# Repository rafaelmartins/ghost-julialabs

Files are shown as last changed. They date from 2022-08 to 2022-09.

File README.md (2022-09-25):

# ghost-julialabs

PCI para o desafio de halloween 2022 do canal [julialabs na Twitch](https://www.twitch.tv/julialabs).

Layout baseado na skin básica de fantasma do jogo Among Us.

## Hardware

### Placa de Circuito Impresso

placa de circuito impresso - frente
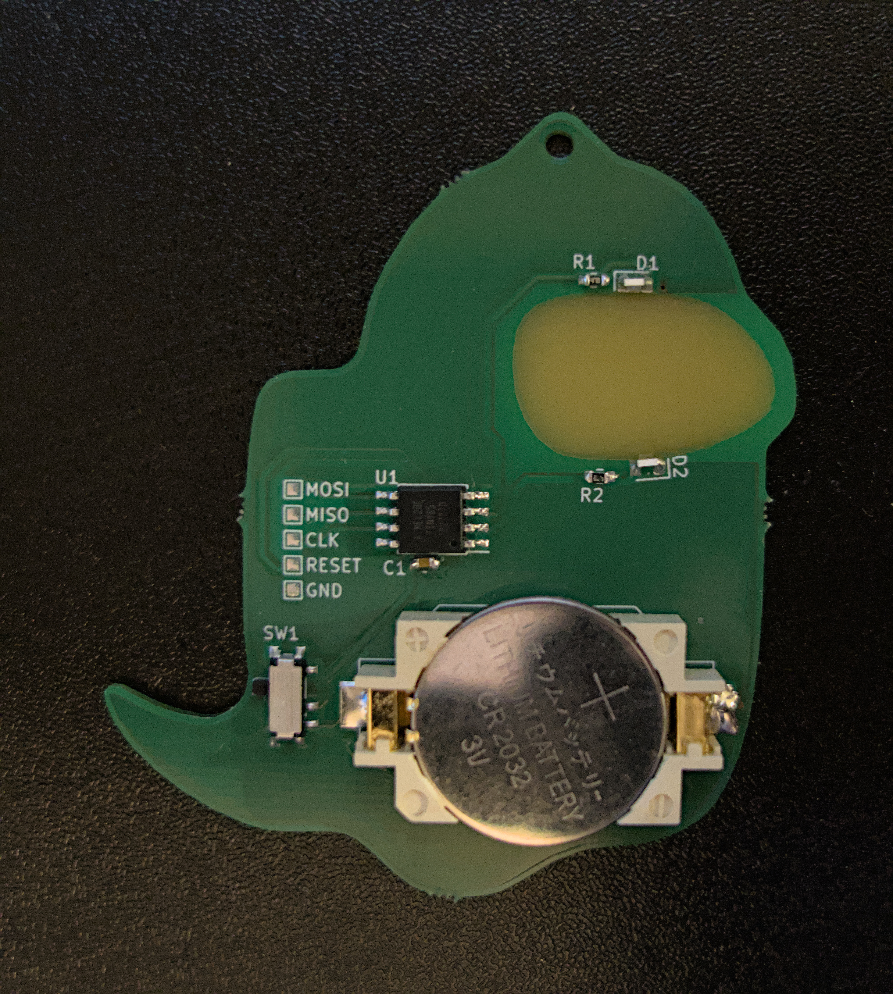
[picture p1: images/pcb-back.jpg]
placa de circuito impresso - verso

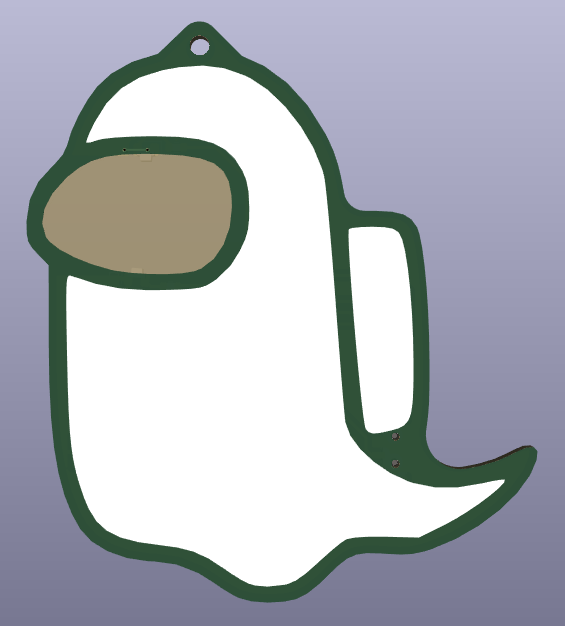
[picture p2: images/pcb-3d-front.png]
placa de circuito impresso - modelo 3d frente

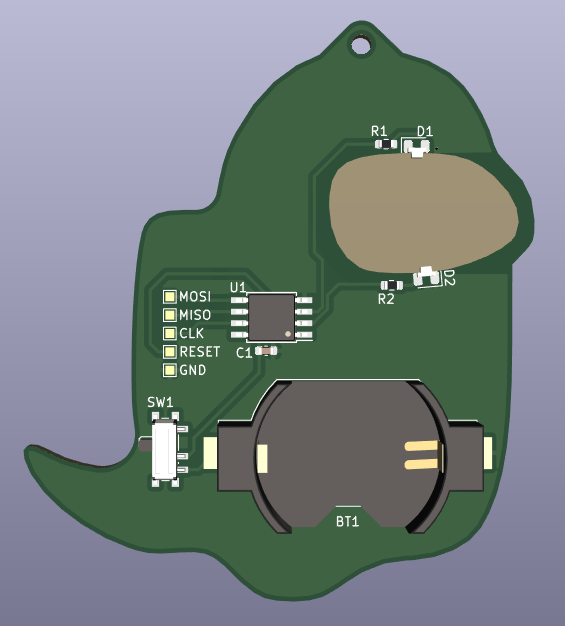
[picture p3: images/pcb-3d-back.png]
placa de circuito impresso - modelo 3d verso


#### Produção

Arquivo `.zip` com Gerbers disponivel [aqui](/pcb/gerber/). Para produzir as placas basta fazer upload do zip no site da [PCBWay](https://www.pcbway.com/) ou similar.

### Esquemático

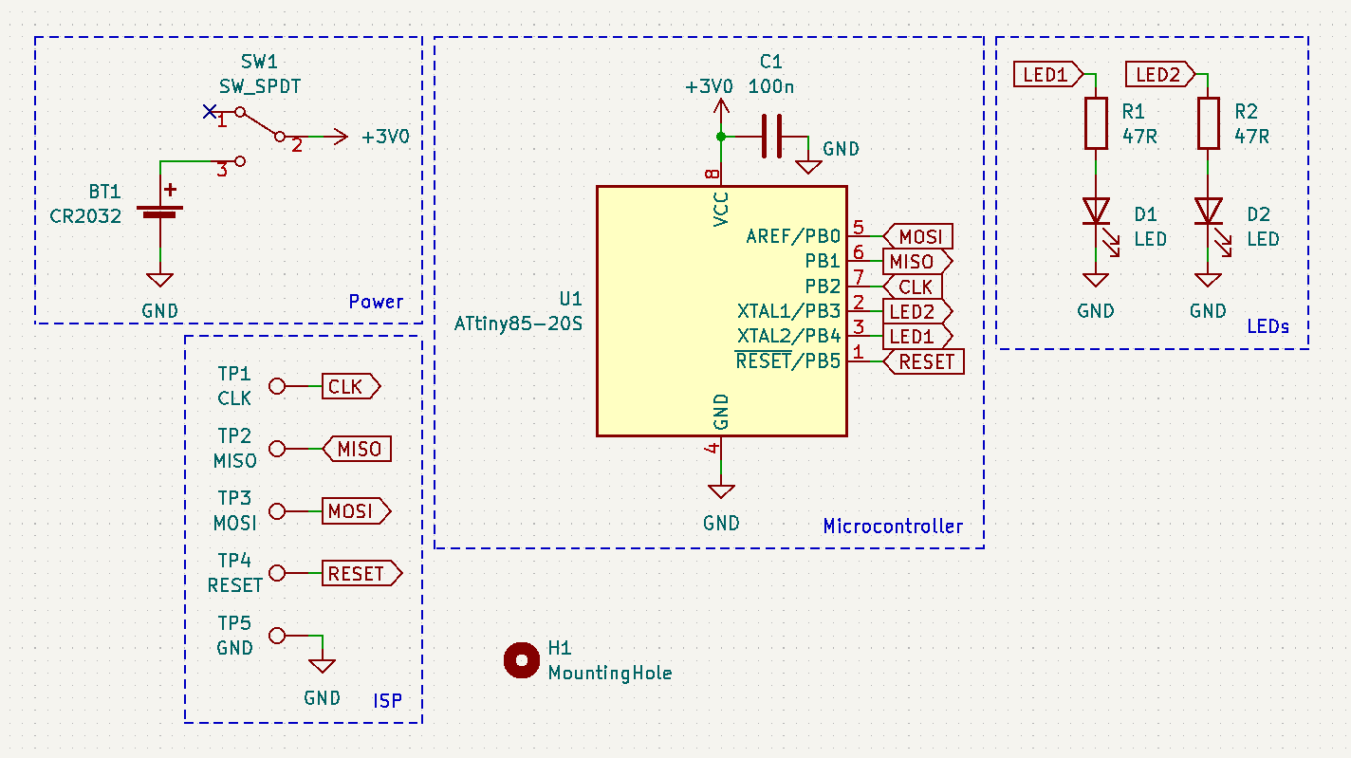
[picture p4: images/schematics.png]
esquemático


### Lista de Materiais

ID     | Description                   | Mouser No.
------ | ----------------------------- | ------------------------------------------------------------------------------
U1     | Microcontrolador ATtiny85-20S | [556-ATTINY85-20SF](https://www.mouser.de/ProductDetail/556-ATTINY85-20SF)
D1     | LED SMD Verde "Side View"     | [710-155060VS75300](https://www.mouser.de/ProductDetail/710-155060VS75300)
D2     | LED SMD Vermelho "Side View"  | [710-155060SS75300](https://www.mouser.de/ProductDetail/710-155060SS75300)
R1, R2 | Resistor SMD 47R 0603         | [603-RC0603FR-0747RL](https://www.mouser.de/ProductDetail/603-RC0603FR-0747RL)
C1     | Capacitor SMD 100nF 0603      | [810-C0603X7S1A104K](https://www.mouser.de/ProductDetail/810-C0603X7S1A104K)
BT1    | Suporte para bateria CR2032   | [534-1058](https://www.mouser.de/ProductDetail/534-1058)
SW1    | Chave SPDT ON-ON              | [611-PCM12SMTR](https://www.mouser.de/ProductDetail/611-PCM12SMTR)

## Software

Acesse o [release mais recente](https://github.com/rafaelmartins/ghost-julialabs/releases/latest) e faça o download do arquivo `ghost-julialabs.hex`. Grave o conteúdo deste arquivo na memória flash do `ATtiny85` da forma que achar mais conveniente. A forma mais popular entre os makers consiste na utilização do [AVRDUDE](https://www.nongnu.org/avrdude/) com um gravador de baixo custo como o [USBasp](https://www.fischl.de/usbasp/). A utilização dos mesmos foge do escopo desse documento.

A seguinte configuração de `fuses` do `ATtiny85` é necessaria para o correto funcionamento (podem ser gravados utilizando a mesma ferramenta que gravou o firmware na memória flash):

```
low=0xE2, high=0x9F, extended=0xFF, lockbit=0xFF
```

## License

Original work is released under the BSD 3-Clause (firmware) and CERN Open Hardware Licence Version 2 - Strongly Reciprocal (pcb).

This project is based on Among Us game artwork, and should be covered by the [Innersloth Fan Creation Policy](https://www.innersloth.com/fan-creation-policy/). Based on drawing from [xcolorings.com (via Pinterest)](https://www.pinterest.com/pin/584834701606097283/).

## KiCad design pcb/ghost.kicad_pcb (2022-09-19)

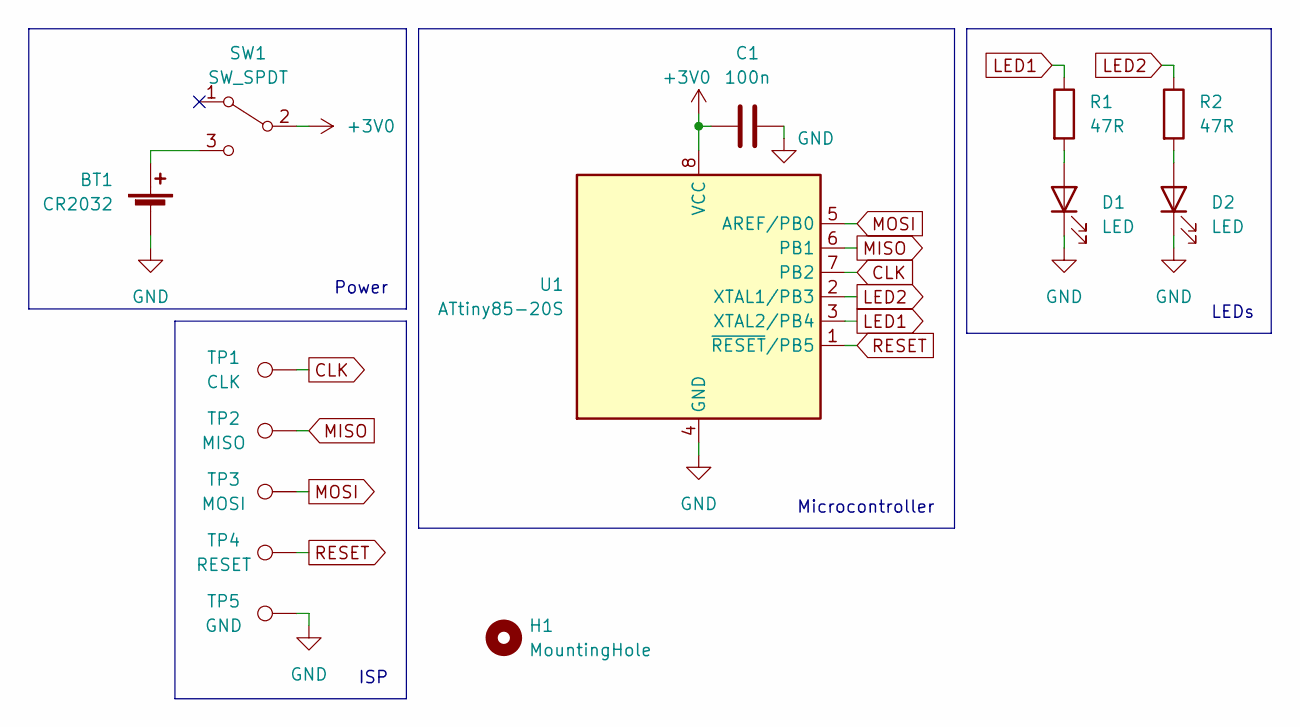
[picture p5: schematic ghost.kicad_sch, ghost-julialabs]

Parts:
BT1: CR2032; BatteryHolder_Keystone_1058_1x2032
C1: 100n; C_0603_1608Metric
D1, D2: LED; LED_0805_2012Metric
H1: MountingHole; MountingHole_2.2mm_M2
R1, R2: 47R; R_0603_1608Metric
SW1: SW_SPDT; SW_SPDT_PCM12
TP1: CLK; TestPoint_Pad_1.0x1.0mm
TP2: MISO; TestPoint_Pad_1.0x1.0mm
TP3: MOSI; TestPoint_Pad_1.0x1.0mm
TP4: RESET; TestPoint_Pad_1.0x1.0mm
TP5: GND; TestPoint_Pad_1.0x1.0mm
U1: ATtiny85-20S; SOIC-8W_5.3x5.3mm_P1.27mm

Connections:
+3V0: C1.1, SW1.2 (B), U1.8 (VCC)
CLK: TP1.1, U1.7 (PB2)
GND: BT1.2 (-), C1.2, D1.1 (K), D2.1 (K), TP5.1, U1.4 (GND)
LED1: R1.1, U1.3 (XTAL2/PB4)
LED2: R2.1, U1.2 (XTAL1/PB3)
MISO: TP2.1, U1.6 (PB1)
MOSI: TP3.1, U1.5 (AREF/PB0)
unnamed: BT1.1 (+), SW1.3 (C)
unnamed: D1.2 (A), R1.2
unnamed: D2.2 (A), R2.2
RESET: TP4.1, U1.1 (~RESET/PB5)

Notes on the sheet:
ISP
Power
LEDs
Microcontroller

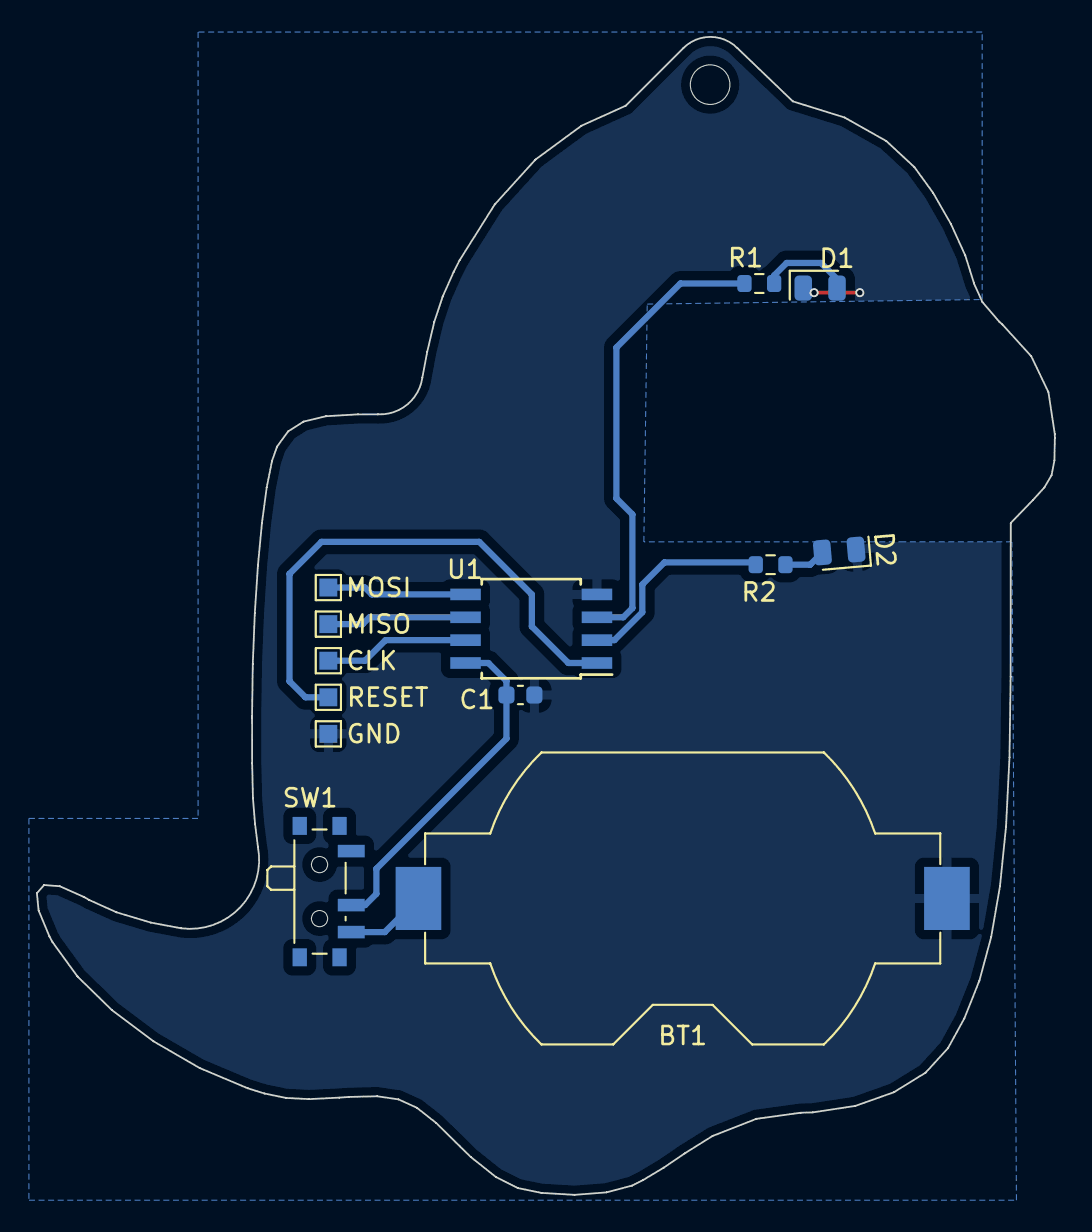
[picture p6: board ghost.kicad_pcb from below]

Board: 2 copper layers, 56.6 x 64.3 mm, 14 parts (13 on the bottom side), 11 nets.

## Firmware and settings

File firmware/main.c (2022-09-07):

#include <avr/interrupt.h>
#include <avr/io.h>
#include <stdbool.h>

static volatile bool up_t0 = false;
static volatile bool up_t1 = false;
static volatile uint8_t counter = 0;
static volatile uint8_t top = 0;

ISR(TIMER0_COMPA_vect)
{
    OCR1B = up_t1 ? counter++ : 0xff - counter++;
    if (counter == 0) {
        up_t1 = !up_t1;
        OCR0A = 10 + (up_t0 ? top++ : 0xf - top++);
        if (top == 0xf) {
            up_t0 = !up_t0;
            top = 0;
        }
    }
}

int
main(void)
{
    DDRB = (1 << PB3) | (1 << PB4);

    TCCR0A = (1 << WGM01);
    TCCR0B = (1 << CS02) | (1 << CS00);
    TIMSK = (1 << OCIE0A);

    TCCR1 = (1 << CS13);
    GTCCR = (1 << PWM1B) | (1 << COM1B0);

    sei();
    while (1);
    return 0;
}

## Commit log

2022-08-25 Commit inicial.
    [ghost.kicad_pcb, ghost.kicad_sch]
2022-09-19 altera resistores dos leds
    [ghost.kicad_pcb, ghost.kicad_sch]
2022-09-25 Atualiza leds utilizados na montagem final
2022-09-25 firmware: desabilita geracao de hex para fuses
2022-09-30 pcb: corrige gerber
